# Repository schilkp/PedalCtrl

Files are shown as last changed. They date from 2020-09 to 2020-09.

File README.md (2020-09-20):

# PedalCtrl
Philipp Schilk 2020

https://github.com/TheSchilk/PedalCtrl

A very simple, PIC12F1572-based, footpedal-controlled, relay 250V Mains switch.

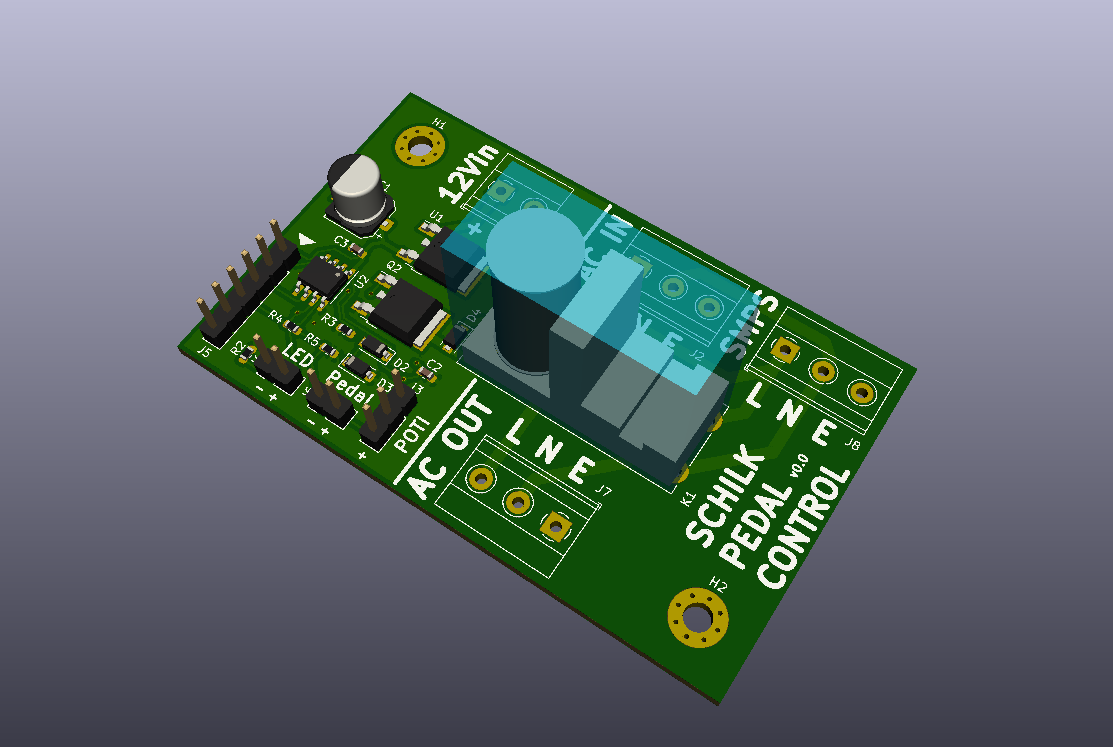
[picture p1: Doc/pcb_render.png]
PCB Render


## Mandatory Warning

Please don't work with mains-connected circuits unless you know what you are doing.

## Status

Waiting for PCB prototype to develop Firmware.

## Details

Allows mains-powered devices to be quickly powered on and off using a footswitch.
Both Line and Neutral are switched.

Pressing the pedal once enables the device and starts an automatic timer controlled
by the potentiometer. Once that timer runs out, or the pedal is pressed again, the 
device will switch back off.

Quickly pressing the pedal twice causes the device to stay permanently powered on until
the pedal is pressed again.

## Production Files
Please see Github 'Releases' for Schematic, Gerbers, Interactive BOM usw.

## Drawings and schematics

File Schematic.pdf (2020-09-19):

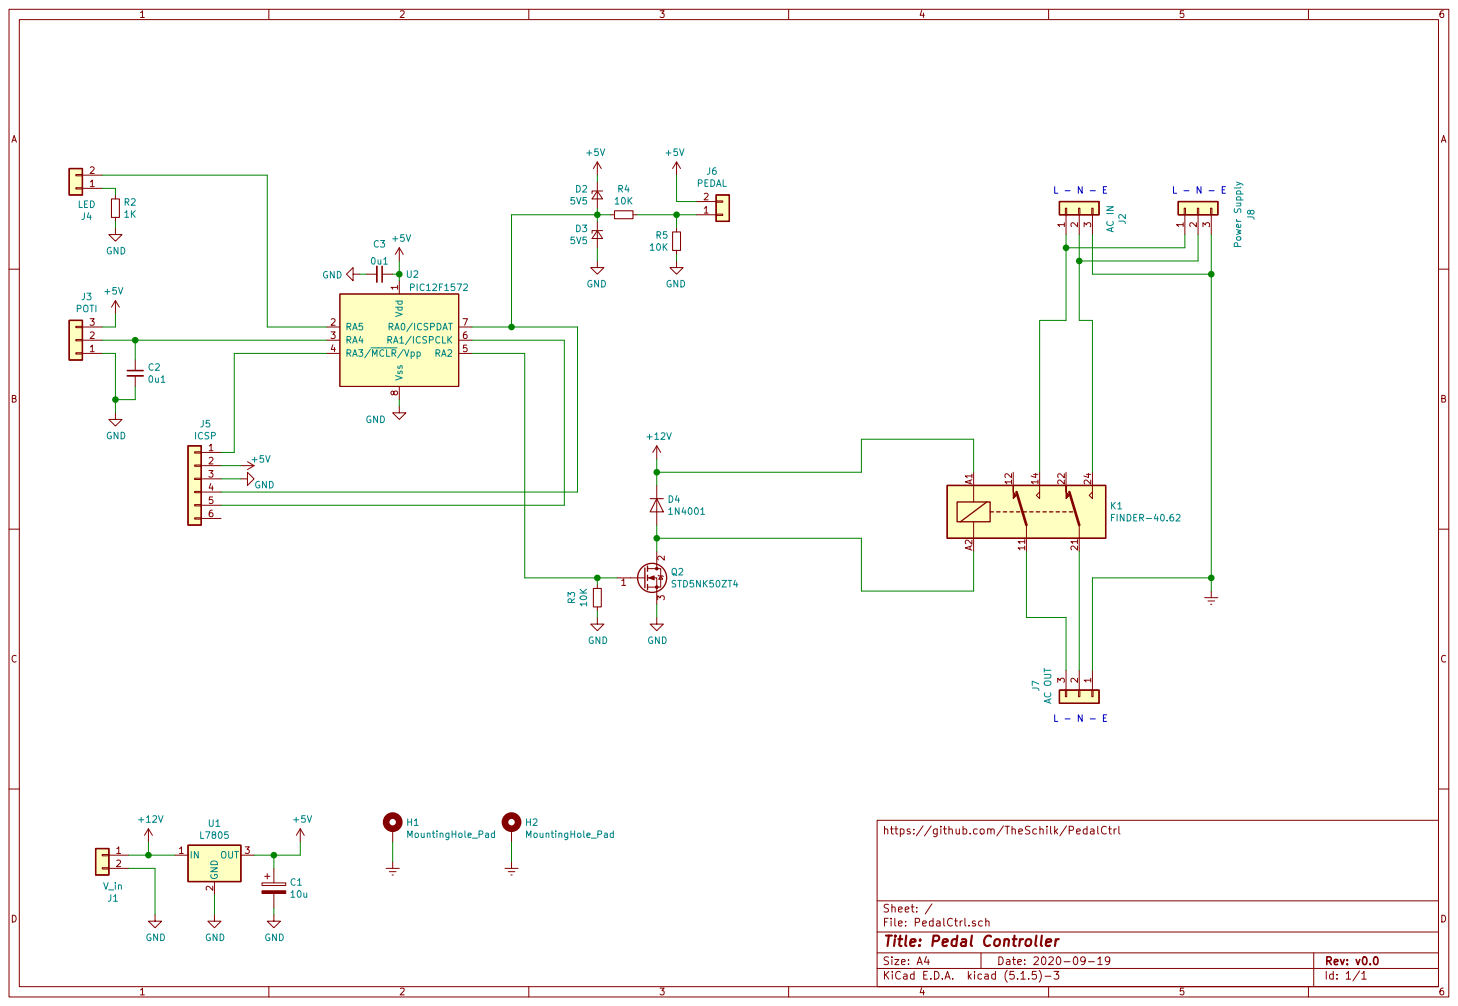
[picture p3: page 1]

1 RA5 2 RA4 3 RA3/MCLR/Vpp 4 RA2 5 RA1/ICSPCLK 6 RA0/ICSPDAT 7 Vss 8 U2PIC12F1572 +5V

Id: 1/1 Title: Pedal Controller File: PedalCtrl.sch Sheet: / https://github.com/TheSchilk/PedalCtrl

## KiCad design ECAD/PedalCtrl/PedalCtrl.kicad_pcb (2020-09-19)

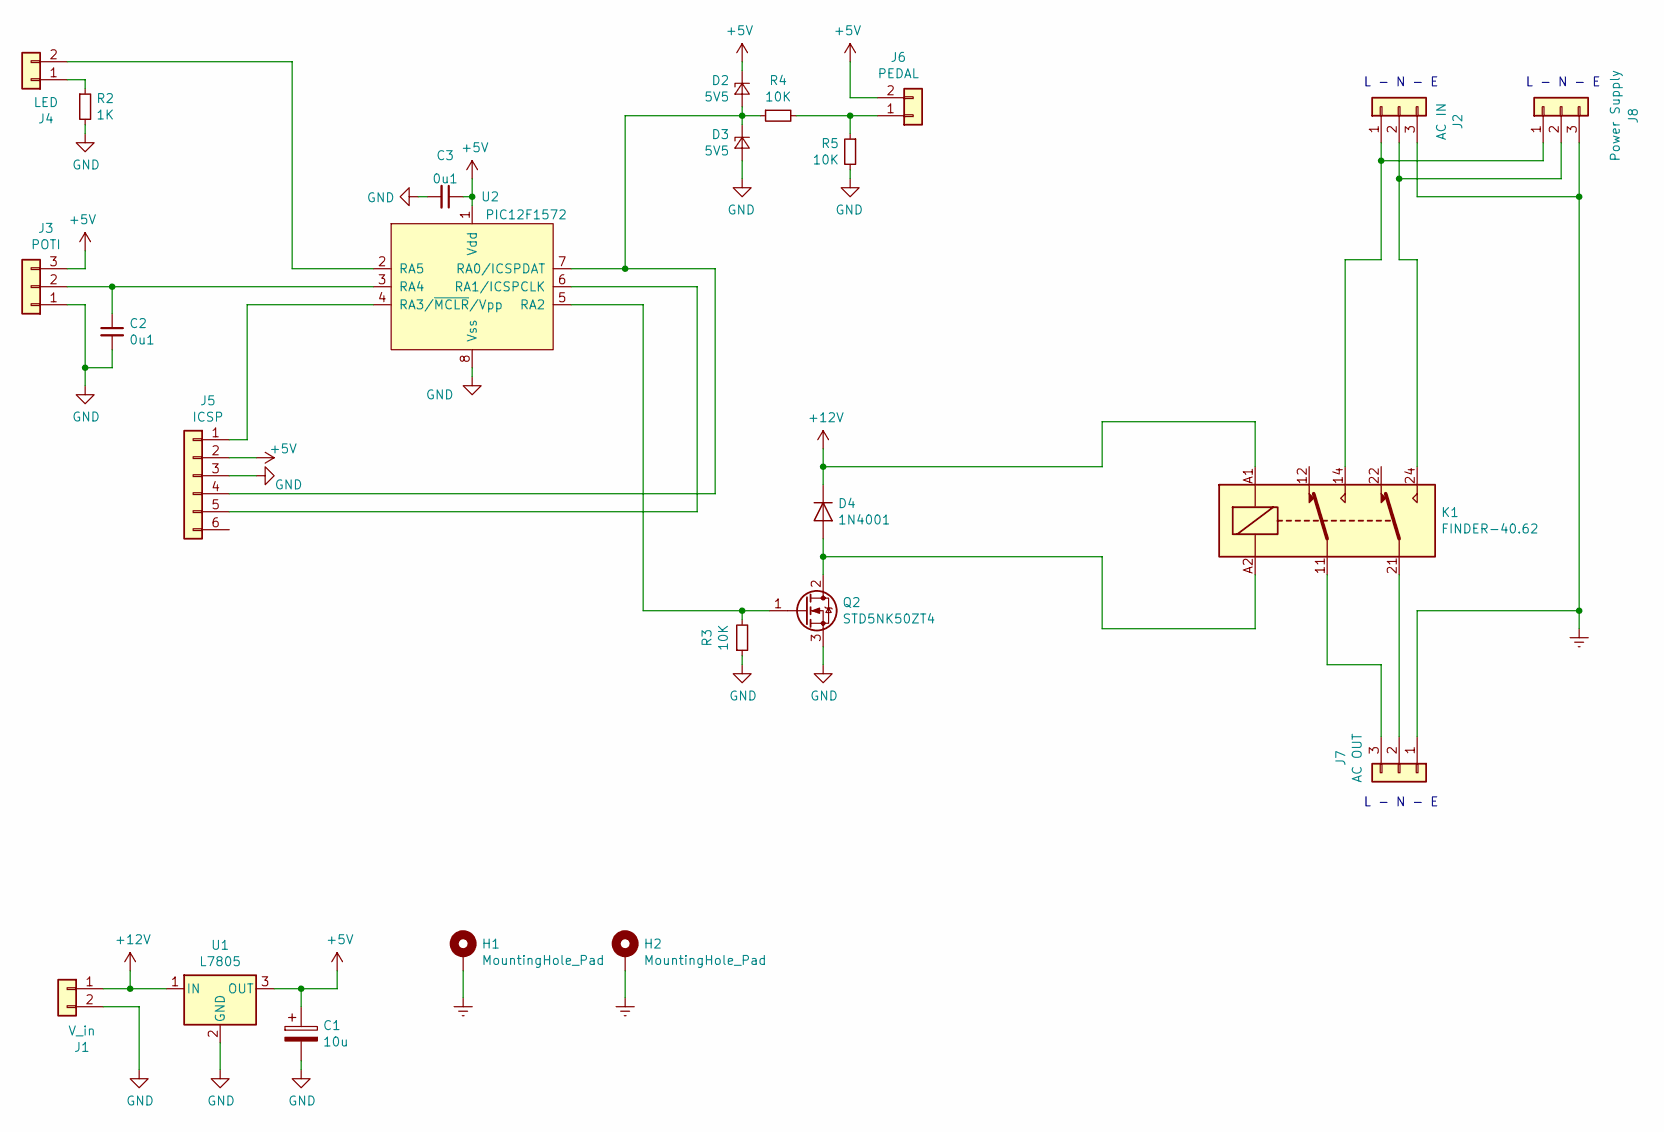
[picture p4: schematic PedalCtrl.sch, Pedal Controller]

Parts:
C1: 10u; CP_Elec_6.3x7.7
C2, C3: 0u1; C_0603_1608Metric
D2, D3: 5V5; D_SOD-123
D4: 1N4001; D_SOD-123F
H1, H2: MountingHole_Pad; MountingHole_3.2mm_M3_Pad_Via
J1: V_in; TerminalBlock_Phoenix_MKDS-1,5-2_1x02_P5.00mm_Horizontal
J2: AC IN; TerminalBlock_Phoenix_MKDS-1,5-3_1x03_P5.00mm_Horizontal
J3: POTI; PinHeader_1x03_P2.54mm_Vertical
J4: LED; PinHeader_1x02_P2.54mm_Vertical
J5: ICSP; PinHeader_1x06_P2.54mm_Vertical
J6: PEDAL; PinHeader_1x02_P2.54mm_Vertical
J7: AC OUT; TerminalBlock_Phoenix_MKDS-1,5-3_1x03_P5.00mm_Horizontal
J8: Power Supply; TerminalBlock_Phoenix_MKDS-1,5-3_1x03_P5.00mm_Horizontal
K1: FINDER-40.62; Relay_DPDT_Finder_40.52
Q2: STD5NK50ZT4; TO-252-2
R2: 1K; R_0603_1608Metric
R3, R4, R5: 10K; R_0603_1608Metric
U1: L7805; TO-252-2
U2: PIC12F1572; SOIC-8_3.9x4.9mm_P1.27mm

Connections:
+5V: C1.1, C3.1, D2.1 (K), J3.3, J5.2, J6.2, U1.3 (OUT), U2.1 (Vdd)
+12V: D4.1 (K), J1.1, K1.A1, U1.1 (IN)
Earth: H1.1, H2.1, J2.3, J7.1, J8.3
GND: C1.2, C2.2, C3.2, D3.2 (A), J1.2, J3.1, J5.3, Q2.3 (S), R2.2, R3.1, R5.2, U1.2 (GND), U2.8 (Vss)
unnamed: C2.1, J3.2, U2.3 (RA4)
unnamed: D2.2 (A), D3.1 (K), J5.4, R4.1, U2.7 (RA0/ICSPDAT)
unnamed: D4.2 (A), K1.A2, Q2.2 (D)
unnamed: J2.1, J8.1, K1.14
unnamed: J2.2, J8.2, K1.24
unnamed: J4.1, R2.1
unnamed: J4.2, U2.2 (RA5)
unnamed: J5.1, U2.4 (RA3/~MCLR~/Vpp)
unnamed: J5.5, U2.6 (RA1/ICSPCLK)
unnamed: J6.1, R4.2, R5.1
unnamed: J7.2, K1.21
unnamed: J7.3, K1.11
unnamed: Q2.1 (G), R3.2, U2.5 (RA2)

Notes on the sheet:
L - N - E

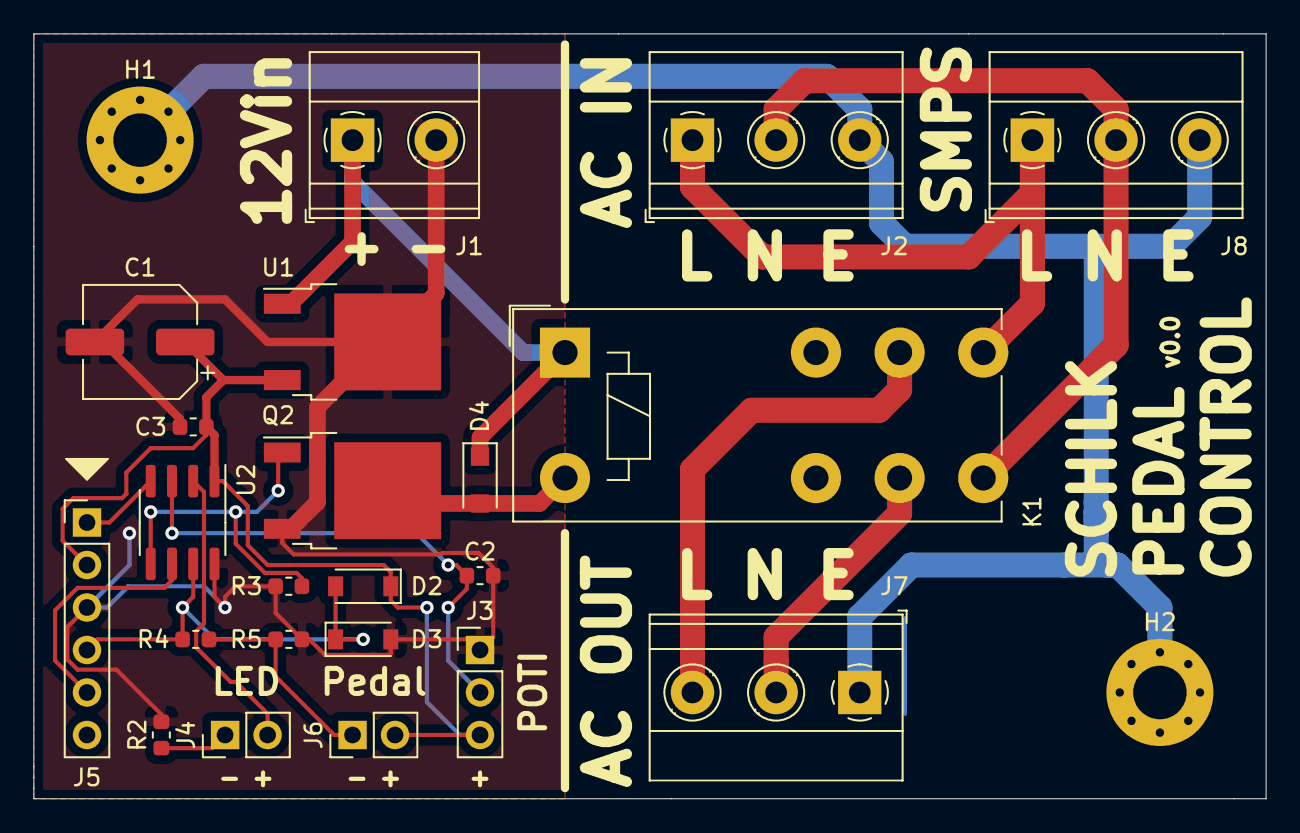
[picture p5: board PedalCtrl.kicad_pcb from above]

Board: 2 copper layers, 73.7 x 45.7 mm, 24 parts (0 on the bottom side), 17 nets.

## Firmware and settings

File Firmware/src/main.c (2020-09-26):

/* 
 * File:   main.c
 * Author: pschilk
 *
 * Created on September 20, 2020, 8:34 AM
 */

// CONFIG1
#pragma config FOSC = INTOSC    // (INTOSC oscillator; I/O function on CLKIN pin)
#pragma config WDTE = ON        // Watchdog Timer Enable (WDT enabled)
#pragma config PWRTE = OFF      // Power-up Timer Enable (PWRT disabled)
#pragma config MCLRE = ON       // MCLR Pin Function Select (MCLR/VPP pin function is MCLR)
#pragma config CP = OFF         // Flash Program Memory Code Protection (Program memory code protection is disabled)
#pragma config BOREN = ON       // Brown-out Reset Enable (Brown-out Reset enabled)
#pragma config CLKOUTEN = OFF   // Clock Out Enable (CLKOUT function is disabled. I/O or oscillator function on the CLKOUT pin)

// CONFIG2
#pragma config WRT = OFF        // Flash Memory Self-Write Protection (Write protection off)
#pragma config PLLEN = OFF      // PLL Enable (4x PLL disabled)
#pragma config STVREN = ON      // Stack Overflow/Underflow Reset Enable (Stack Overflow or Underflow will cause a Reset)
#pragma config BORV = LO        // Brown-out Reset Voltage Selection (Brown-out Reset Voltage (Vbor), low trip point selected.)
#pragma config LPBOREN = OFF    // Low Power Brown-out Reset enable bit (LPBOR is disabled)
#pragma config LVP = ON         // Low-Voltage Programming Enable (Low-voltage programming enabled)

#include <pic.h>
#include <stdint.h>

#define DEBOUNCE_TIME  25  // Time inputs are ignored after input in 10s of ms
#define DBLPRESS_TIME  400 // Max interval to count as 'double press' in 10s of ms
#define BLINK_TIME     100 // LED Blink period in 10s of ms

// Coefficients to determine min and max length:
// Min length in seconds: ADCSCALE_BASE / 100
// Max length in seconds: (ADCSCALE_BASE + ADCSCALE_MULT*2^10) / 100
#define ADCSCALE_MULT 90
#define ADCSCALE_BASE 12000


uint32_t debounce_count;
uint8_t debounce_prevstate;

uint32_t on_timer;
uint32_t press_timer;

uint32_t blink_timer;
uint8_t  blink_state;

typedef enum{
    state_off,
    state_timer,
    state_on         
}STATE_T;

STATE_T state;



int main(int argc, char** argv) {
    CLRWDT();
    
    // ===== WDT & CLK =====
    // Using internal MF OSC at 500khz
    OSCCONbits.SPLLEN = 0;
    OSCCONbits.IRCF = 0b0111;
    OSCCONbits.SCS = 0b10;
    
    // Have WDT reset every 512ms
    WDTCONbits.WDTPS = 0b01001;
    
    // ===== Config GPIO =====
    TRISAbits.TRISA0 = 1; // Pedal Input
    TRISAbits.TRISA2 = 0; // Relay Ouput
    TRISAbits.TRISA4 = 1; // Poti Input
    TRISAbits.TRISA5 = 0; // LED Output
    
    // Clear all outputs
    LATA = 0x0; 
    
    // Set RA4 as only analog input
    ANSELA = 0x0;
    ANSELAbits.ANSA4 = 1;
    
    // Disable all pullups, all pins push-pull,
    // no slewrate limiting
    WPUA = 0x0;
    ODCONA = 0x0;
    SLRCONA = 0x0;
    
    // ===== Config ADC ======
    ADCON0bits.CHS = 0b00011; // Select CH3 (RA4)
    
    ADCON1bits.ADFM = 1; // Right-justified result
    ADCON1bits.ADCS = 0b000; // Conversion Clk Fosc/2
    ADCON1bits.ADPREF = 0b00; // VDD is positive voltage refernce
    
    ADCON2bits.TRIGSEL = 0; // No Automatic triggering
    
    ADCON0bits.ADON = 1; // Turn on ADC
    
    ADCON0bits.GO = 1; // Start conversion
    
    // ===== Setup Variables =====
    debounce_count = 0;
    debounce_prevstate = PORTAbits.RA0;
    state = state_off;
    blink_state = 0;
    
    // ===== Config Regular interrupt =====
    // Setup Timer 0 to overflow at aprox. 120Hz and trigger interrupt
    OPTION_REGbits.TMR0CS = 0; // Timer 0 clocked from Fosc/4
    OPTION_REGbits.PSA = 0;    // Timer 0 has prescalar
    OPTION_REGbits.PS = 0b01;  // Timer 0 prescalar is /4
    
    INTCONbits.GIE = 1;    // Interupts enabled.
    INTCONbits.TMR0IE = 1; // Timer 0 interrupt enabled
    
    
    
    while(1){
        NOP();
    }
    return (EXIT_SUCCESS);
}

uint32_t result;

void __interrupt() ISR(void){
    CLRWDT(); // pet the watchdog..
    
    // Handle ADC
    if(!ADCON0bits.GO_nDONE){
        // ADC Conversion finished
        result = (ADRESH << 8) | ADRESL;
        
        // Start next conversion
        ADCON0bits.GO_nDONE = 1;
    }
    
    uint8_t did_press = 0;
    
	// Handle De-bounce
	if(debounce_count == 0){ // Ready for next event
        // Determine if input changed and we should time out again
        if(debounce_prevstate != PORTAbits.RA0){
            debounce_count = DEBOUNCE_TIME;
            debounce_prevstate = PORTAbits.RA0;
            
            if(PORTAbits.RA0){
                did_press = 1;
            }
        }
        
    } else { // Still timed out
        debounce_count--;
        did_press = 0;
    }
  
    NOP();
    
    switch(state){
        case state_off:
            LATAbits.LATA2 = 0;
            LATAbits.LATA5 = 0;
            
            if(did_press){
                // Go to timer state.
                state = state_timer;
                
                // Start timer
                on_timer = ADCSCALE_BASE+(ADCSCALE_MULT*result);
                
                // Reset Blinking
                blink_state = 1;
                blink_timer = BLINK_TIME;
                
                // Start double-press timer
                press_timer = DBLPRESS_TIME;
            }
            break;
 
        case state_timer:
            
            LATAbits.LATA2 = 1;
            LATAbits.LATA5 = blink_state;
            
            if(blink_timer == 0){
                blink_timer = BLINK_TIME;
                
                blink_state = (blink_state) ? 0 : 1;    
            } else {
                blink_timer--;
            }
            
            if(did_press){
                if(press_timer == 0){
                    // Turn off
                    state = state_off;
                    break;
                } else {
                    // Go to always on
                    state = state_on;
                    break;
                }
            }
            
            if(on_timer == 0){
                state = state_off;
                break;
            } else {
                on_timer--;
            }
            
            if(press_timer != 0){
                press_timer--;
            }
            break;
            
        case state_on:
            
            PORTAbits.RA2 = 1;
            PORTAbits.RA5 = 1;
            
            if(did_press){
                state = state_off;
            }
            
            break;
        default:
            state = state_off;
    }
    
    // Clear flags and reset GIE
    INTCONbits.TMR0IF = 0;
    INTCONbits.GIE = 1;
}

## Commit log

2020-09-20 Moved KiCad .gitignore
2020-09-26 Finished firmware. Better UI timings & LED blinks
